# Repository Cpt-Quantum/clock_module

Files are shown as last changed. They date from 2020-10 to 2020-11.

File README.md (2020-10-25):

# Clock Module
This repo contains the schematic and PCB design for a clock module that features both a variable frequency clock (from a 555 timer) and a single step mode. The schematic is based very closely on Ben Eater's design (https://eater.net/8bit/clock), and will be used alongside his breadboard 6502 project.

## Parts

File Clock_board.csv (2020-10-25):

Reference | Quantity | Value | Footprint | Datasheet | Mfr Part # | Supplier | Supplier Part #
C3 C2 C4 | 3 | 10nF | Capacitor_THT:C_Disc_D4.7mm_W2.5mm_P5.00mm | ~ | CD1H103KC94ER1D000 | LCSC | C263180
C6 C7 C8 C5 | 4 | 0.1uF | Capacitor_THT:C_Disc_D4.7mm_W2.5mm_P5.00mm | ~ | CD1H104MC9BEF4D000 | LCSC | C263185
C9 C1 | 2 | 1uF | Capacitor_THT:C_Disc_D4.7mm_W2.5mm_P5.00mm | ~ | CD1H105MC9BEF4E000 | LCSC | C263189
H1 H3 H2 H4 | 4 | MountingHole | MountingHole:MountingHole_2.5mm | ~
J1 J3 J4 J5 J2 | 5 | Conn_01x02 | Connector_PinHeader_2.54mm:PinHeader_1x02_P2.54mm_Vertical | ~
R4 R6 R2 R3 R1 | 5 | 1kR | Resistor_THT:R_Axial_DIN0204_L3.6mm_D1.6mm_P5.08mm_Horizontal | ~
R5 | 1 | 1MR | Resistor_THT:R_Axial_DIN0204_L3.6mm_D1.6mm_P5.08mm_Horizontal | ~
RV1 | 1 | 1M_POT | Potentiometer_THT:Potentiometer_Runtron_RM-065_Vertical | ~
SW1 | 1 | SW_Push | Button_Switch_THT:SW_PUSH_6mm_H5mm | ~
SW2 | 1 | SW_Push_DPDT | chinesium:DPDT-Latching-PB12E06371 | https://datasheet.lcsc.com/szlcsc/1810231713_GANGYUAN-PB12E06371_C194402.pdf | PB12E06371 | LCSC | C194402
U3 U1 U2 | 3 | NE555 | Package_DIP:DIP-8_W7.62mm | https://datasheet.lcsc.com/szlcsc/1912111437_HGSEMI-NE555N_C398063.pdf | NE555N | LCSC | C398063
U4 | 1 | SN74HC08N | Package_DIP:DIP-14_W7.62mm | https://datasheet.lcsc.com/szlcsc/1810081044_Texas-Instruments-SN74HC08N_C2887.pdf | SN74HC08N | LCSC | C2887
U5 | 1 | 74HC04N | Package_DIP:DIP-14_W7.62mm | https://datasheet.lcsc.com/szlcsc/2004021807_HGSEMI-74HC04N_C507192.pdf | 74HC04N | LCSC | C507192
U6 | 1 | SN74HC32N | Package_DIP:DIP-14_W7.62mm | https://datasheet.lcsc.com/szlcsc/1810201813_Texas-Instruments-SN74HC32N_C2894.pdf | SN74HC32N | LCSC | C2894

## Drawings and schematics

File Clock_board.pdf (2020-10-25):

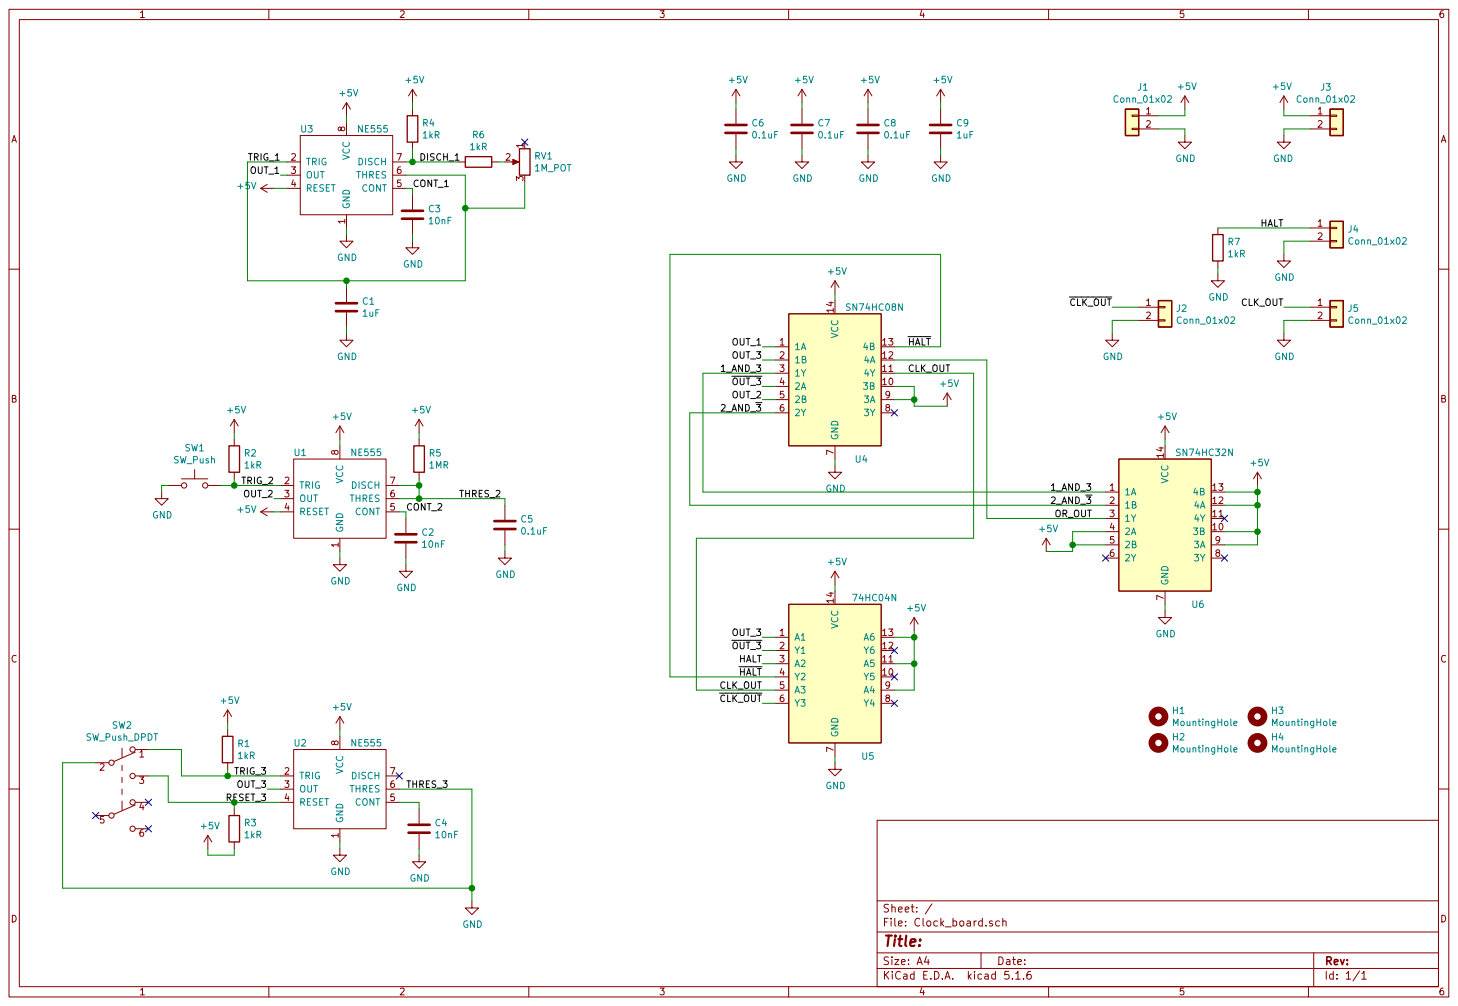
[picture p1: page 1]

1 TRIG 2 OUT 3 RESET 4 CONT 5 THRES 6 DISCH VCC 7 U3 8NE555 C2

1 TRIG 2 OUT 3 RESET 4 CONT 5 THRES 6 DISCH VCC 7 U1 8NE555 GND

1 TRIG 2 OUT 3 RESET 4 CONT 5 THRES 6 DISCH VCC 7 U2 8NE555 C5

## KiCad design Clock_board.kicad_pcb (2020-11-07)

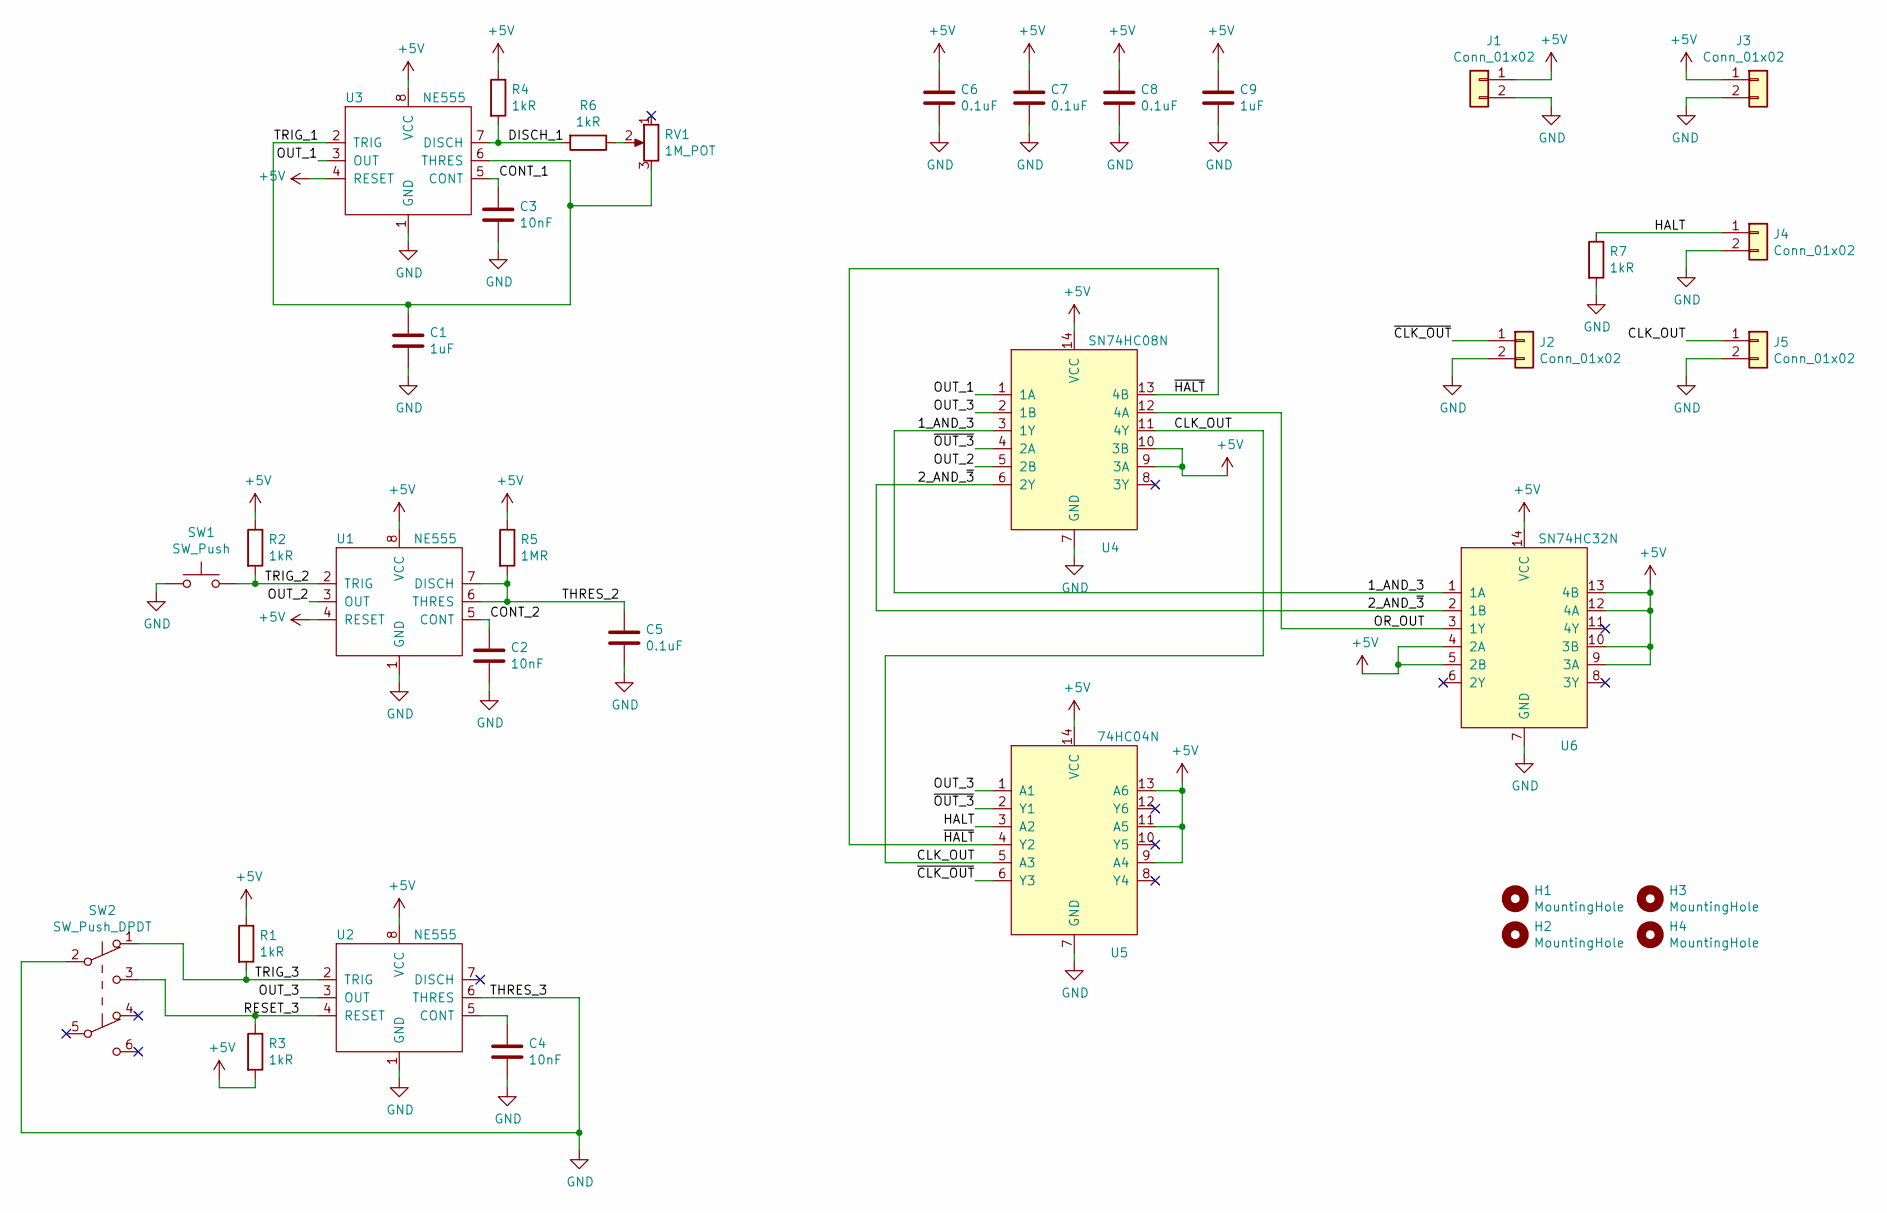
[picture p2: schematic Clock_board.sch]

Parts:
C1, C9: 1uF; C_Disc_D4.7mm_W2.5mm_P5.00mm; Mfr Part # CD1H105MC9BEF4E000
C2, C3, C4: 10nF; C_Disc_D4.7mm_W2.5mm_P5.00mm; Mfr Part # CD1H103KC94ER1D000
C5, C6, C7, C8: 0.1uF; C_Disc_D4.7mm_W2.5mm_P5.00mm; Mfr Part # CD1H104MC9BEF4D000
H1, H2, H3, H4: MountingHole; MountingHole_2.5mm
J1, J2, J3, J4, J5: Conn_01x02; PinHeader_1x02_P2.54mm_Vertical
R1, R2, R3, R4, R6, R7: 1kR; R_Axial_DIN0207_L6.3mm_D2.5mm_P7.62mm_Horizontal
R5: 1MR; R_Axial_DIN0207_L6.3mm_D2.5mm_P7.62mm_Horizontal
RV1: 1M_POT; Potentiometer_Runtron_RM-065_Vertical
SW1: SW_Push; SW_PUSH_6mm_H5mm
SW2: SW_Push_DPDT; DPDT-Latching-PB12E06371; Mfr Part # PB12E06371
U1, U2, U3: NE555; DIP-8_W7.62mm; Mfr Part # NE555N
U4: SN74HC08N; DIP-14_W7.62mm; Mfr Part # SN74HC08N
U5: 74HC04N; DIP-14_W7.62mm; Mfr Part # 74HC04N
U6: SN74HC32N; DIP-14_W7.62mm; Mfr Part # SN74HC32N

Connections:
+5V: C6.1, C7.1, C8.1, C9.1, J1.1, J3.1, R1.1, R2.1, R3.2, R4.1, R5.1, U1.4 (RESET), U1.8 (VCC), U2.8 (VCC), U3.4 (RESET), U3.8 (VCC), U4.9 (3A), U4.10 (3B), U4.14 (VCC), U5.9 (A4), U5.11 (A5), U5.13 (A6), U5.14 (VCC), U6.4 (2A), U6.5 (2B), U6.9 (3A), U6.10 (3B), U6.12 (4A), U6.13 (4B), U6.14 (VCC)
/1_AND_3: U4.3 (1Y), U6.1 (1A)
/2_AND_~3: U4.6 (2Y), U6.2 (1B)
/CLK_OUT: J5.1, U4.11 (4Y), U5.5 (A3)
/CONT_1: C3.1, U3.5 (CONT)
/CONT_2: C2.1, U1.5 (CONT)
/DISCH_1: R4.2, R6.2, U3.7 (DISCH)
/HALT: J4.1, R7.1, U5.3 (A2)
/OR_OUT: U4.12 (4A), U6.3 (1Y)
/OUT_1: U3.3 (OUT), U4.1 (1A)
/OUT_2: U1.3 (OUT), U4.5 (2B)
/OUT_3: U2.3 (OUT), U4.2 (1B), U5.1 (A1)
/RESET_3: R3.1, SW2.3 (C), U2.4 (RESET)
/THRES_2: C5.1, R5.2, U1.6 (THRES), U1.7 (DISCH)
/TRIG_1: C1.1, RV1.3, U3.2 (TRIG), U3.6 (THRES)
/TRIG_2: R2.2, SW1.2, U1.2 (TRIG)
/TRIG_3: R1.2, SW2.1 (A), U2.2 (TRIG)
/~CLK_OUT: J2.1, U5.6 (Y3)
/~HALT: U4.13 (4B), U5.4 (Y2)
/~OUT_3: U4.4 (2A), U5.2 (Y1)
GND: C1.2, C2.2, C3.2, C4.2, C5.2, C6.2, C7.2, C8.2, C9.2, J1.2, J2.2, J3.2, J4.2, J5.2, R7.2, SW1.1, SW2.2 (B), U1.1 (GND), U2.1 (GND), U2.6 (THRES), U3.1 (GND), U4.7 (GND), U5.7 (GND), U6.7 (GND)
unnamed: C4.1, U2.5 (CONT)
unnamed: R6.1, RV1.2

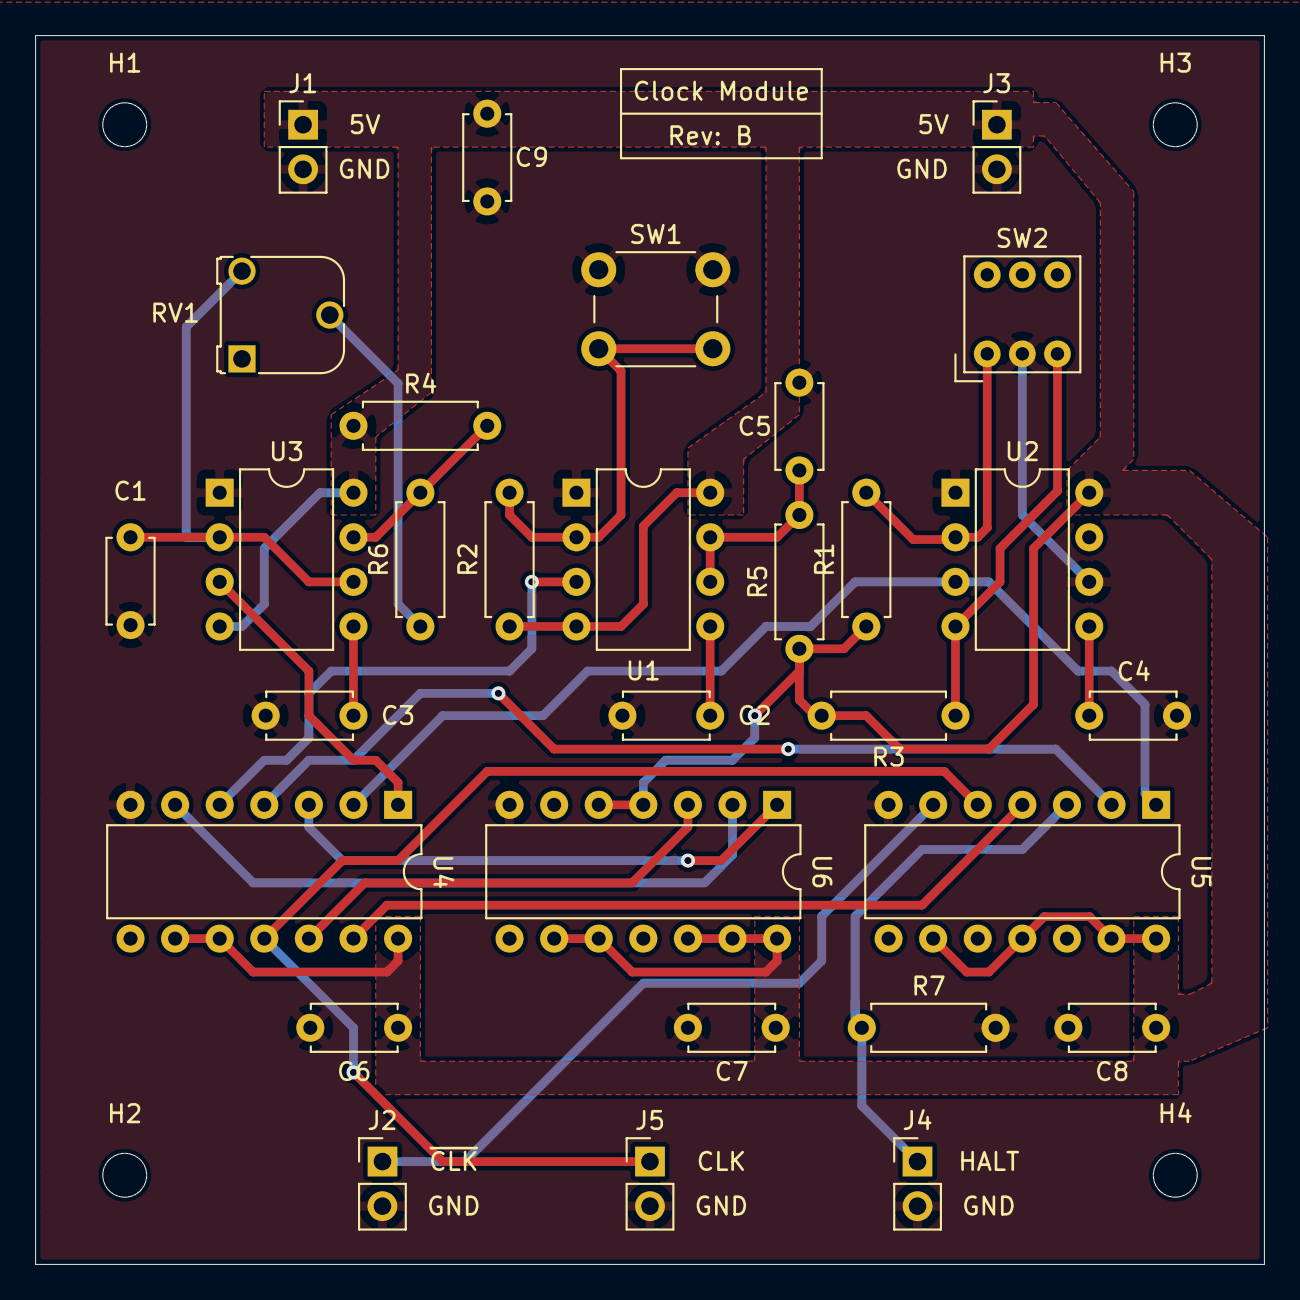
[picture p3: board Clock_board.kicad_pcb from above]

Board: 2 copper layers, 70.0 x 70.0 mm, 34 parts (0 on the bottom side), 23 nets.

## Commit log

2020-10-25 Initial Rev A files commit
    [Clock_board.csv, Clock_board.kicad_pcb, Clock_board.sch]
2020-11-07 Fixed the resistor footprints and changed revision to B
    [Clock_board.kicad_pcb]
